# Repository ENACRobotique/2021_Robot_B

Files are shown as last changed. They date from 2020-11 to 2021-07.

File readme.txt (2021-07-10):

Code utilisée pour la coupe lors de l'année 2021 - sail the world.

Fonctionne assez aléatoirement pour le robot(probablement du à des soucis mécaniques).
Parfois, les états s'enchainent trop rapidement.

Documentation sur doxygen (lancer le index.html dans le dossier documentation_doxygen) pour savoir ce qui est réutilisable.

Flowchart global dans documentation_doxygen - vue_globale_code_2021

Le code utilisée lors de la coupe est dans Decision-IA, mais il est dégueu. Un code un peu plus clean avec la docu à jour pour usage ultérieur est(ou sera pour l'instant...) dans master.

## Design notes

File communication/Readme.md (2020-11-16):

# Communication

# Serialization

Messages serialization/deserialization is done with protobuf.

`def.proto` contains the messages definitions.

Generate python files with : `protoc --python_out=./ def.proto`

See python tutorial: https://developers.google.com/protocol-buffers/docs/pythontutorial

The teensy will use the [nanopb](https://github.com/nanopb/nanopb) library.

# Encapsulation

Encapsulation is handled by `serialcom.py` with the following format:

Encapsulation

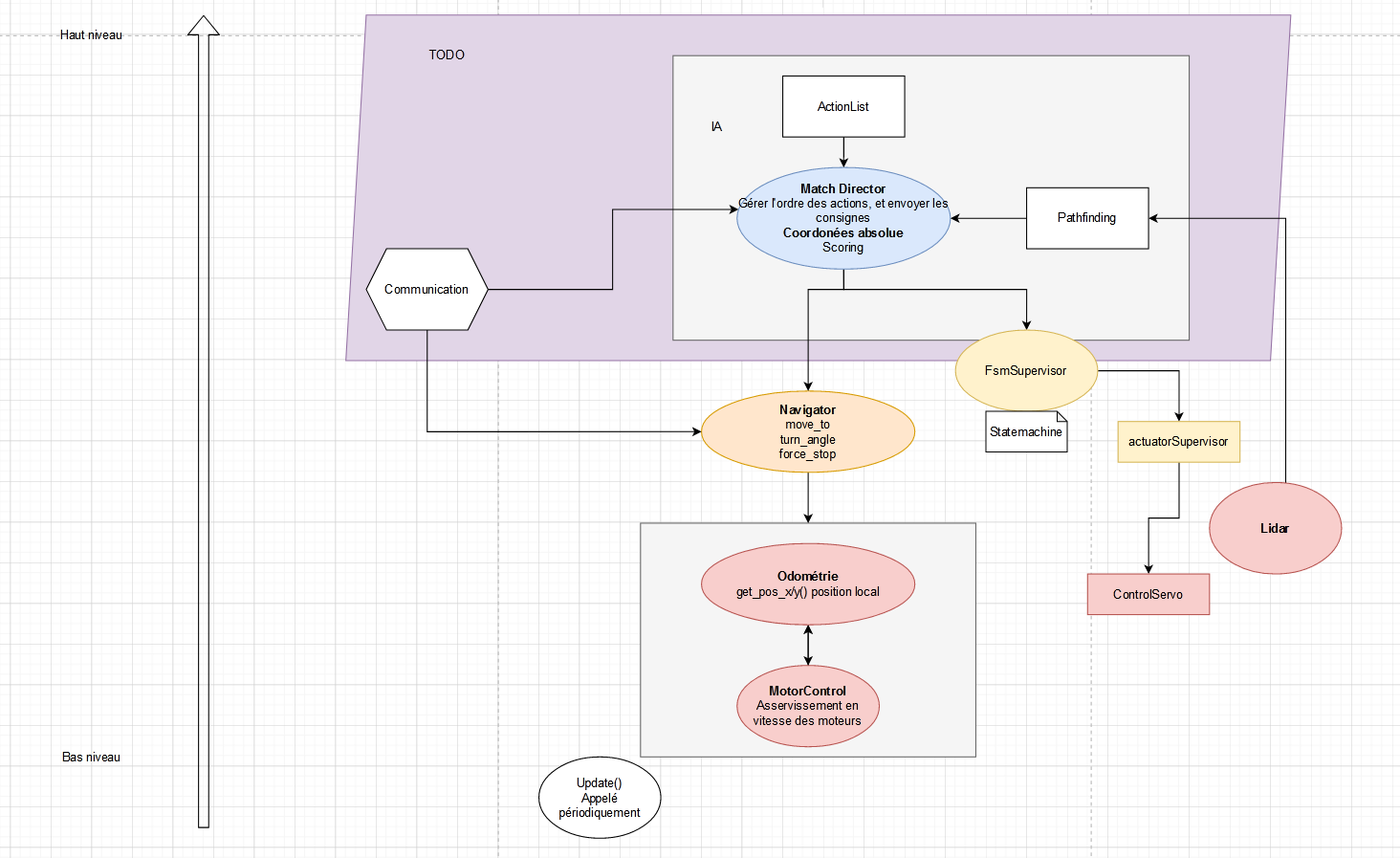
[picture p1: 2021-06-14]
vue_globale_code_2021.png

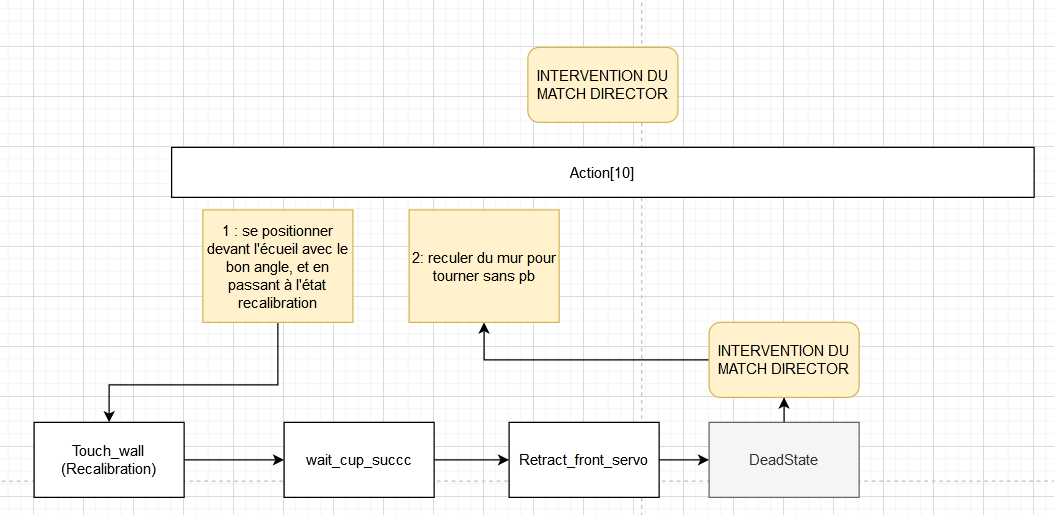
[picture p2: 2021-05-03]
base/src/ai/flowchat example matchdirector.png

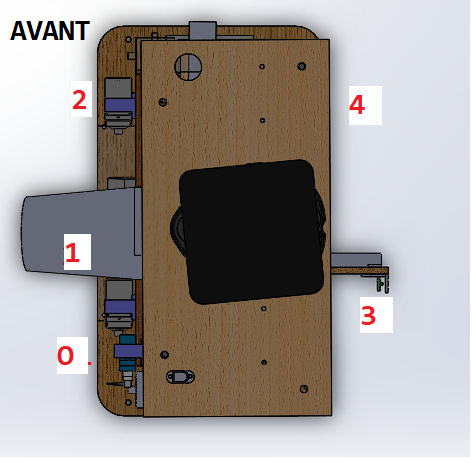
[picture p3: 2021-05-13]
kicad_robot/Numérotation servo capteur.png

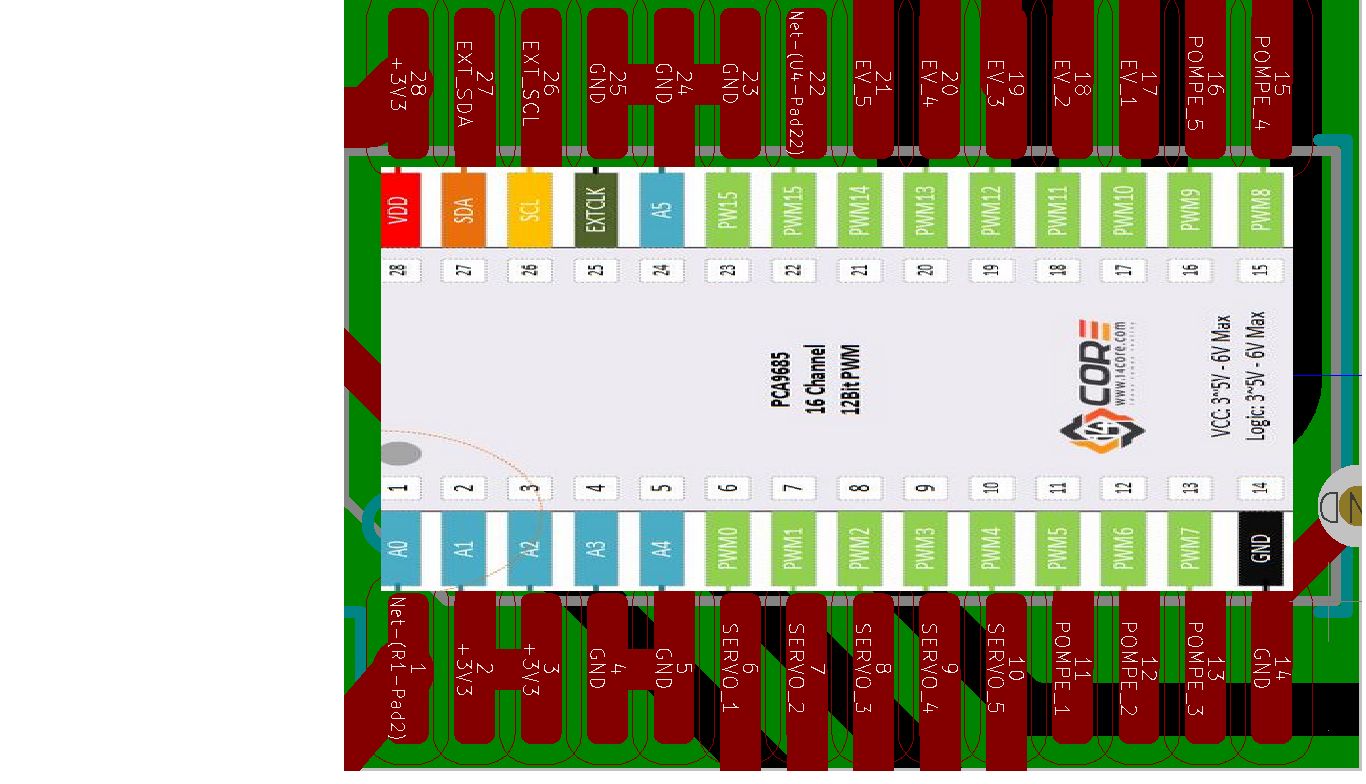
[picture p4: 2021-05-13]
kicad_robot/schéma PCA8595 PWM.png

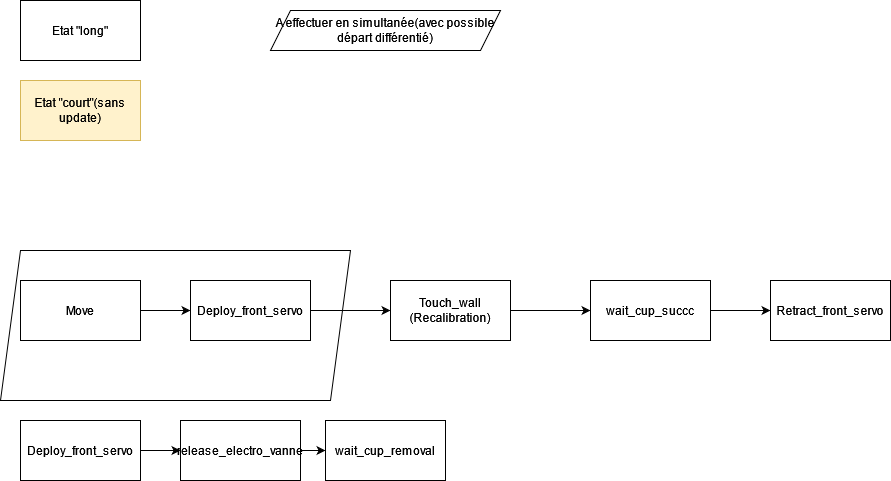
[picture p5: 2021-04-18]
base/src/stateMachine/diagramme state Machine.png

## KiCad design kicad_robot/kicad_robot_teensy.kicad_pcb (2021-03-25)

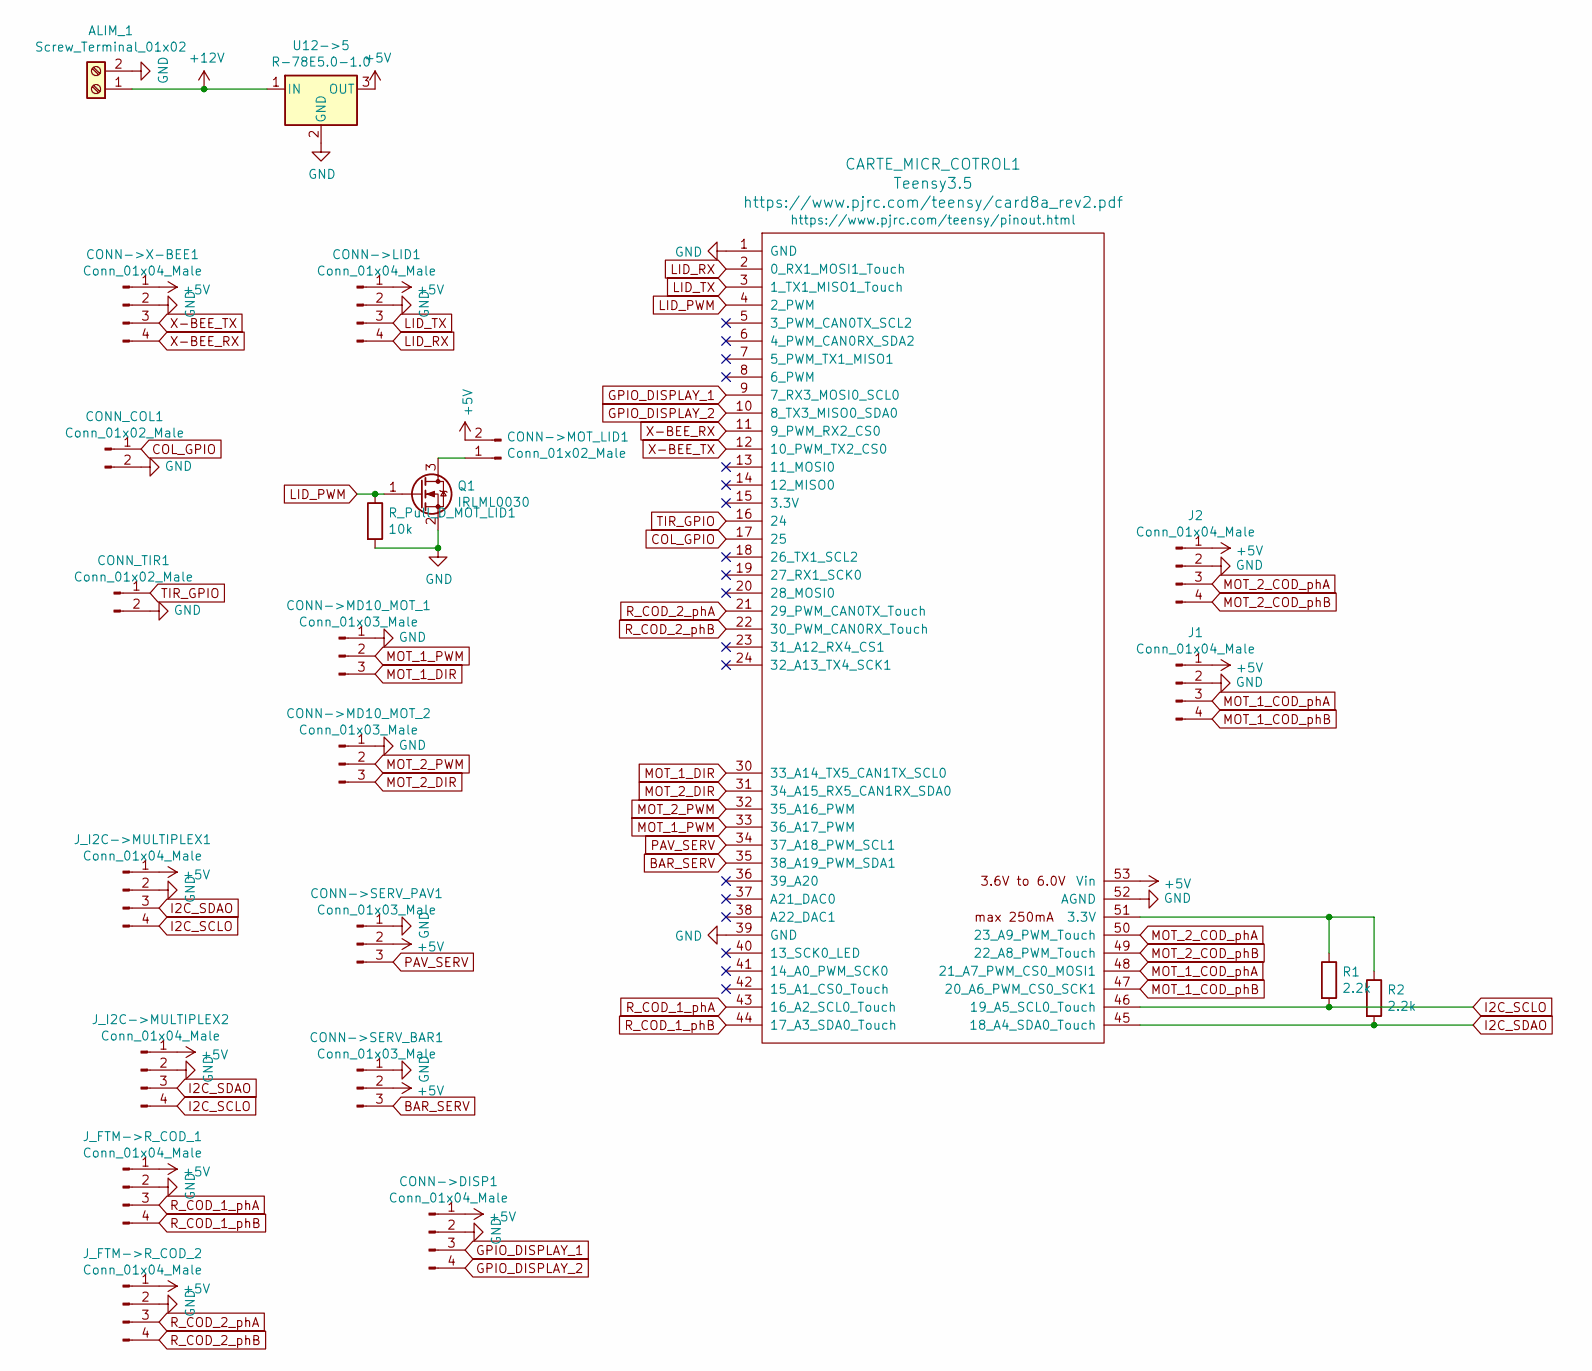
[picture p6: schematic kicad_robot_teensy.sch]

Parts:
ALIM_1: Screw_Terminal_01x02; TerminalBlock_bornier-2_P5.08mm
CARTE_MICR_COTROL1: Teensy3.5; Teensy35_36
CONN->DISP1: Conn_01x04_Male; JST_XH_B4B-XH-A_1x04_P2.50mm_Vertical
CONN->LID1: Conn_01x04_Male; JST_XH_B4B-XH-A_1x04_P2.50mm_Vertical
CONN->MD10_MOT_1, CONN->MD10_MOT_2: Conn_01x03_Male; JST_XH_B3B-XH-A_1x03_P2.50mm_Vertical
CONN->MOT_LID1: Conn_01x02_Male; JST_XH_B2B-XH-A_1x02_P2.50mm_Vertical
CONN->SERV_BAR1: Conn_01x03_Male; PinHeader_1x03_P2.54mm_Vertical
CONN->SERV_PAV1: Conn_01x03_Male; PinHeader_1x03_P2.54mm_Vertical
CONN->X-BEE1: Conn_01x04_Male; JST_XH_B4B-XH-A_1x04_P2.50mm_Vertical
CONN_COL1: Conn_01x02_Male; JST_XH_B2B-XH-A_1x02_P2.50mm_Vertical
CONN_TIR1: Conn_01x02_Male; JST_XH_B2B-XH-A_1x02_P2.50mm_Vertical
J1, J2: Conn_01x04_Male; JST_XH_B4B-XH-A_1x04_P2.50mm_Vertical
J_FTM->R_COD_1, J_FTM->R_COD_2: Conn_01x04_Male; JST_XH_B4B-XH-A_1x04_P2.50mm_Vertical
J_I2C->MULTIPLEX1, J_I2C->MULTIPLEX2: Conn_01x04_Male; JST_XH_B4B-XH-A_1x04_P2.50mm_Vertical
Q1: IRLML0030; SOT-23
R1, R2: 2.2k; R_0603_1608Metric_Pad0.98x0.95mm_HandSolder
R_Pull_D_MOT_LID1: 10k; R_0603_1608Metric_Pad0.98x0.95mm_HandSolder
U12->5: R-78E5.0-1.0; Converter_DCDC_RECOM_R-78E-0.5_THT

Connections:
+5V: CARTE_MICR_COTROL1.53 (Vin), CONN->DISP1.1, CONN->LID1.1, CONN->MOT_LID1.2, CONN->SERV_BAR1.2, CONN->SERV_PAV1.2, CONN->X-BEE1.1, J1.1, J2.1, J_FTM->R_COD_1.1, J_FTM->R_COD_2.1, J_I2C->MULTIPLEX1.1, J_I2C->MULTIPLEX2.1, U12->5.3 (OUT)
+12V: ALIM_1.1, U12->5.1 (IN)
BAR_SERV: CARTE_MICR_COTROL1.35 (38_A19_PWM_SDA1), CONN->SERV_BAR1.3
COL_GPIO: CARTE_MICR_COTROL1.17 (25), CONN_COL1.1
GND: ALIM_1.2, CARTE_MICR_COTROL1.1 (GND), CARTE_MICR_COTROL1.39 (GND), CARTE_MICR_COTROL1.52 (AGND), CONN->DISP1.2, CONN->LID1.2, CONN->MD10_MOT_1.1, CONN->MD10_MOT_2.1, CONN->SERV_BAR1.1, CONN->SERV_PAV1.1, CONN->X-BEE1.2, CONN_COL1.2, CONN_TIR1.2, J1.2, J2.2, J_FTM->R_COD_1.2, J_FTM->R_COD_2.2, J_I2C->MULTIPLEX1.2, J_I2C->MULTIPLEX2.2, Q1.2 (S), R_Pull_D_MOT_LID1.2, U12->5.2 (GND)
GPIO_DISPLAY_1: CARTE_MICR_COTROL1.9 (7_RX3_MOSI0_SCL0), CONN->DISP1.3
GPIO_DISPLAY_2: CARTE_MICR_COTROL1.10 (8_TX3_MISO0_SDA0), CONN->DISP1.4
I2C_SCLO: CARTE_MICR_COTROL1.46 (19_A5_SCL0_Touch), J_I2C->MULTIPLEX1.4, J_I2C->MULTIPLEX2.4, R1.2
I2C_SDAO: CARTE_MICR_COTROL1.45 (18_A4_SDA0_Touch), J_I2C->MULTIPLEX1.3, J_I2C->MULTIPLEX2.3, R2.2
LID_PWM: CARTE_MICR_COTROL1.4 (2_PWM), Q1.1 (G), R_Pull_D_MOT_LID1.1
LID_RX: CARTE_MICR_COTROL1.2 (0_RX1_MOSI1_Touch), CONN->LID1.4
LID_TX: CARTE_MICR_COTROL1.3 (1_TX1_MISO1_Touch), CONN->LID1.3
MOT_1_COD_phA: CARTE_MICR_COTROL1.48 (21_A7_PWM_CS0_MOSI1), J1.3
MOT_1_COD_phB: CARTE_MICR_COTROL1.47 (20_A6_PWM_CS0_SCK1), J1.4
MOT_1_DIR: CARTE_MICR_COTROL1.30 (33_A14_TX5_CAN1TX_SCL0), CONN->MD10_MOT_1.3
MOT_1_PWM: CARTE_MICR_COTROL1.33 (36_A17_PWM), CONN->MD10_MOT_1.2
MOT_2_COD_phA: CARTE_MICR_COTROL1.50 (23_A9_PWM_Touch), J2.3
MOT_2_COD_phB: CARTE_MICR_COTROL1.49 (22_A8_PWM_Touch), J2.4
MOT_2_DIR: CARTE_MICR_COTROL1.31 (34_A15_RX5_CAN1RX_SDA0), CONN->MD10_MOT_2.3
MOT_2_PWM: CARTE_MICR_COTROL1.32 (35_A16_PWM), CONN->MD10_MOT_2.2
unnamed: CARTE_MICR_COTROL1.51 (3.3V), R1.1, R2.1
unnamed: CONN->MOT_LID1.1, Q1.3 (D)
PAV_SERV: CARTE_MICR_COTROL1.34 (37_A18_PWM_SCL1), CONN->SERV_PAV1.3
R_COD_1_phA: CARTE_MICR_COTROL1.43 (16_A2_SCL0_Touch), J_FTM->R_COD_1.3
R_COD_1_phB: CARTE_MICR_COTROL1.44 (17_A3_SDA0_Touch), J_FTM->R_COD_1.4
R_COD_2_phA: CARTE_MICR_COTROL1.21 (29_PWM_CAN0TX_Touch), J_FTM->R_COD_2.3
R_COD_2_phB: CARTE_MICR_COTROL1.22 (30_PWM_CAN0RX_Touch), J_FTM->R_COD_2.4
TIR_GPIO: CARTE_MICR_COTROL1.16 (24), CONN_TIR1.1
X-BEE_RX: CARTE_MICR_COTROL1.11 (9_PWM_RX2_CS0), CONN->X-BEE1.4
X-BEE_TX: CARTE_MICR_COTROL1.12 (10_PWM_TX2_CS0), CONN->X-BEE1.3

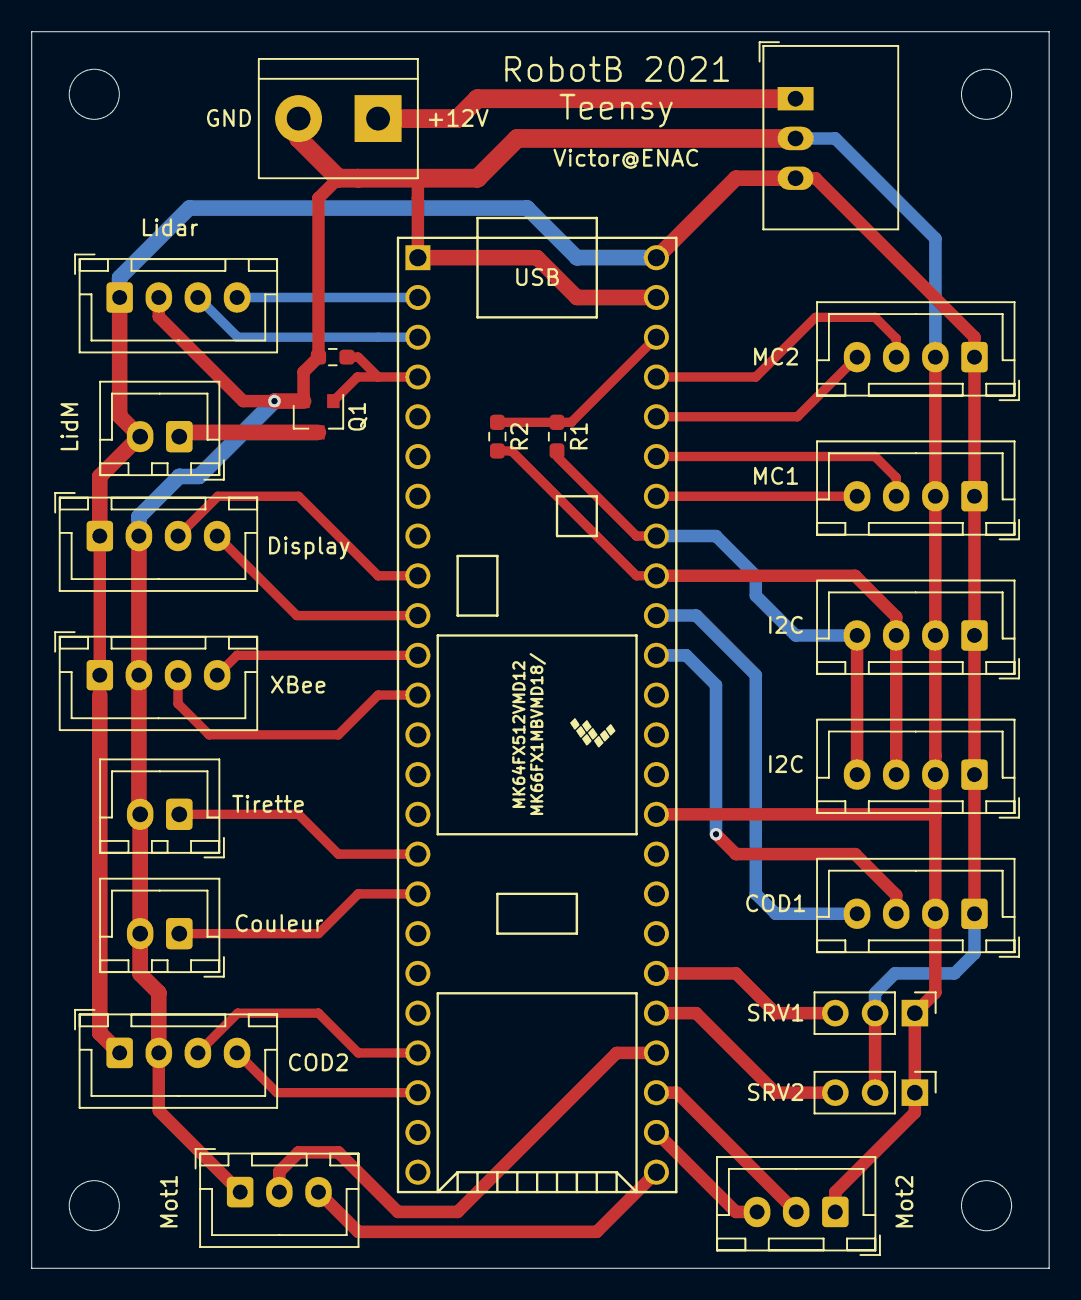
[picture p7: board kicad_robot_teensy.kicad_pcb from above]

Board: 2 copper layers, 65.0 x 79.0 mm, 23 parts (0 on the bottom side), 30 nets.

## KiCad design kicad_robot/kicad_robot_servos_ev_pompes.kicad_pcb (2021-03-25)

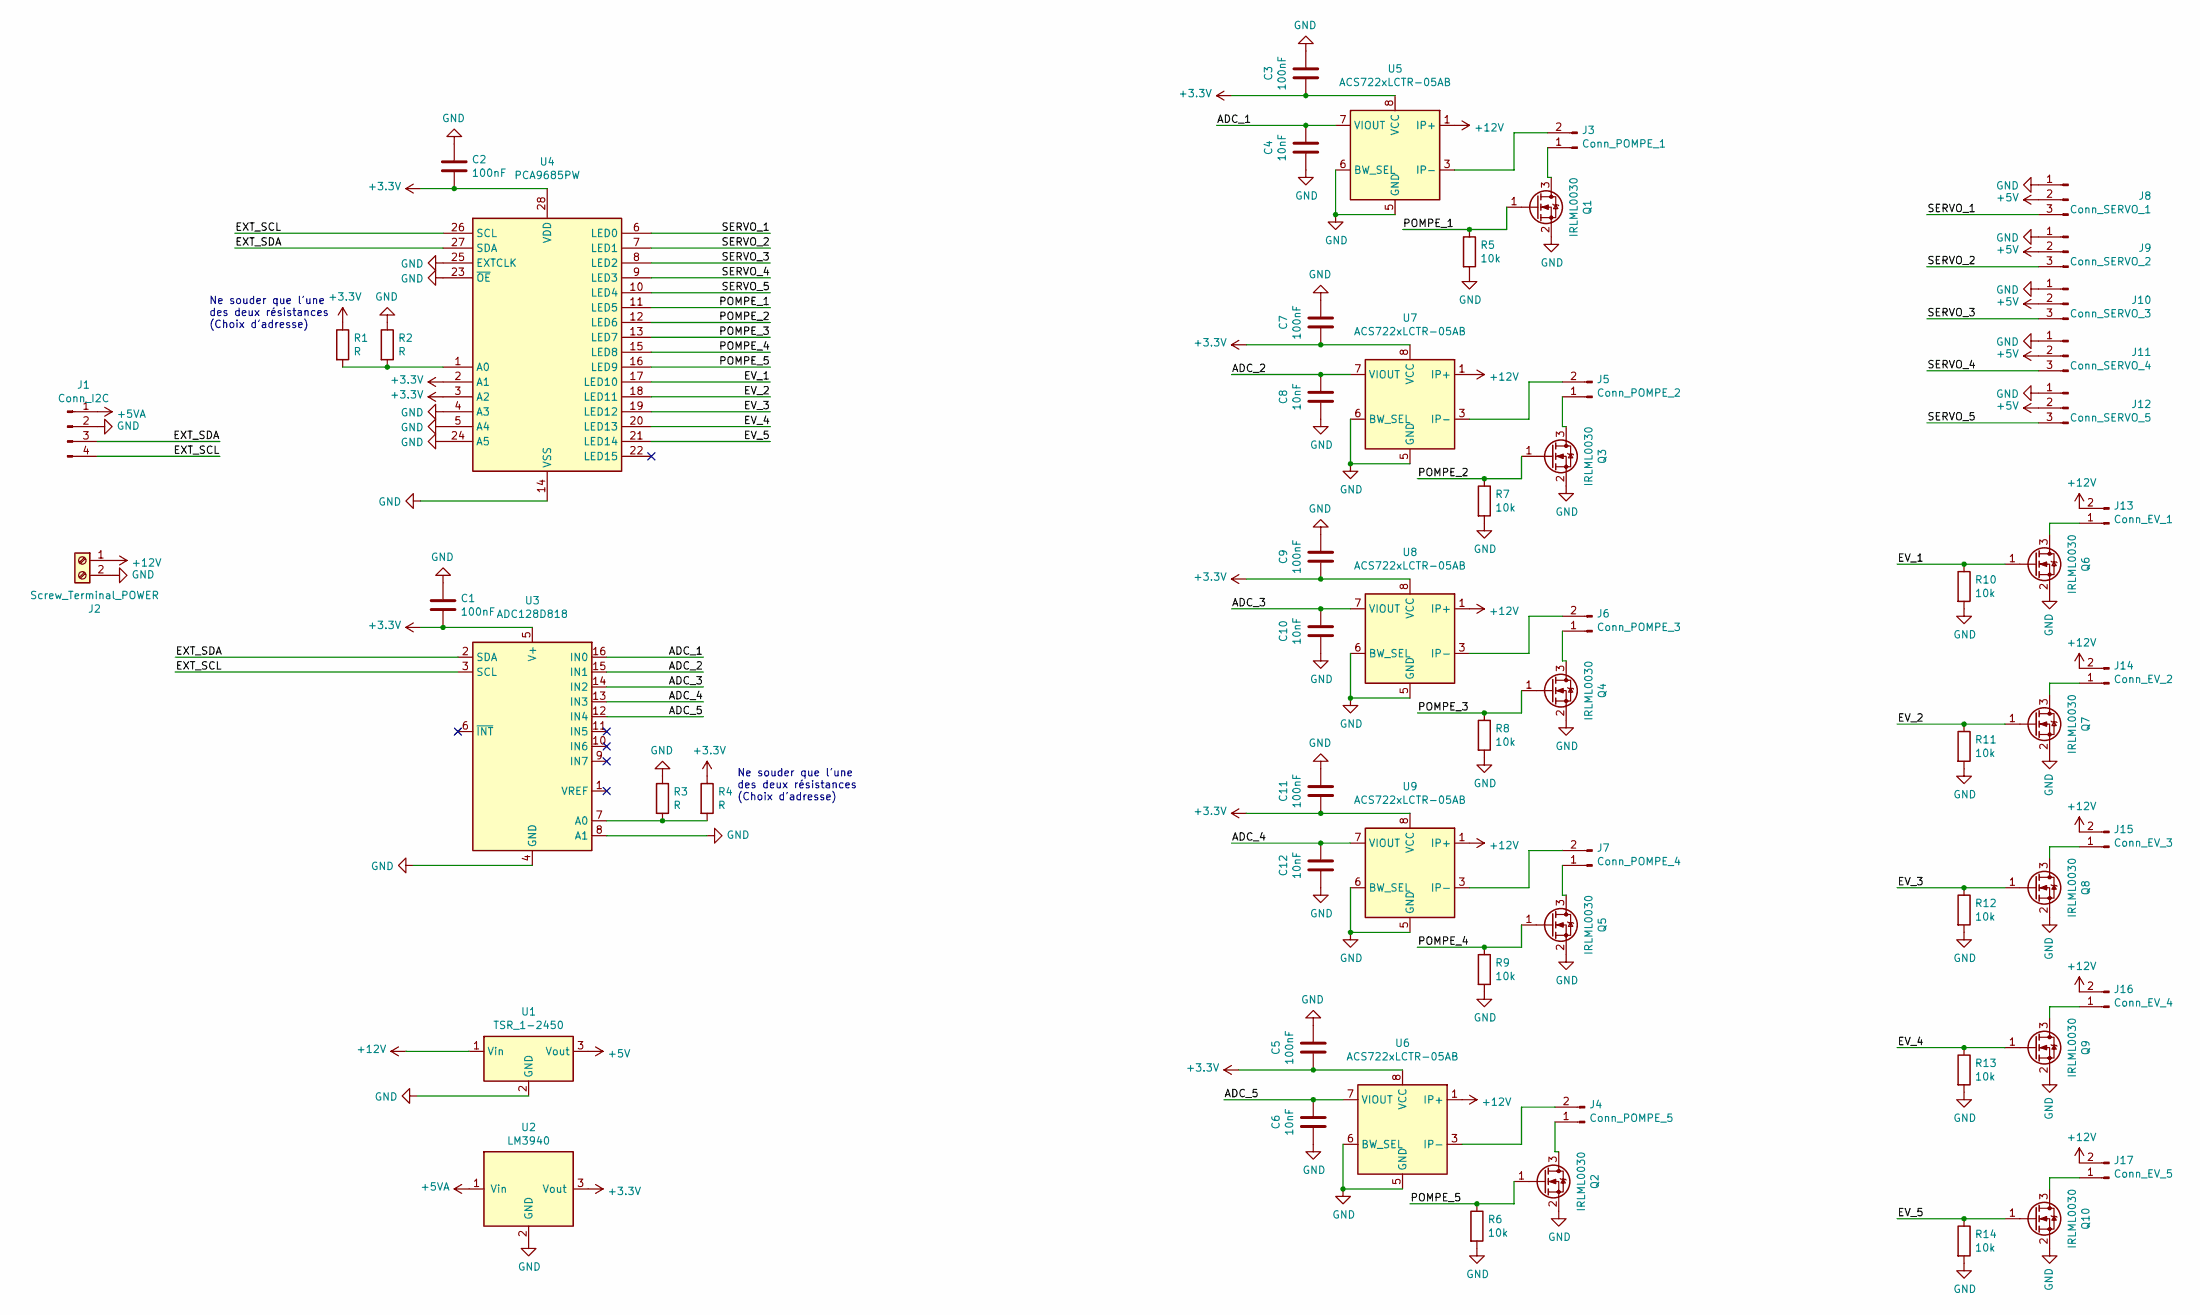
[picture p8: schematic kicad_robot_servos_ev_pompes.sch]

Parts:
C1, C2, C3, C5, C7, C9, C11: 100nF; C_0603_1608Metric_Pad1.08x0.95mm_HandSolder
C4, C6, C8, C10, C12: 10nF; C_0603_1608Metric_Pad1.08x0.95mm_HandSolder
J1: Conn_I2C; JST_XH_B4B-XH-A_1x04_P2.50mm_Vertical
J2: Screw_Terminal_POWER; TerminalBlock_bornier-2_P5.08mm
J3: Conn_POMPE_1; JST_XH_B2B-XH-A_1x02_P2.50mm_Vertical
J4: Conn_POMPE_5; JST_XH_B2B-XH-A_1x02_P2.50mm_Vertical
J5: Conn_POMPE_2; JST_XH_B2B-XH-A_1x02_P2.50mm_Vertical
J6: Conn_POMPE_3; JST_XH_B2B-XH-A_1x02_P2.50mm_Vertical
J7: Conn_POMPE_4; JST_XH_B2B-XH-A_1x02_P2.50mm_Vertical
J8: Conn_SERVO_1; PinHeader_1x03_P2.54mm_Vertical
J9: Conn_SERVO_2; PinHeader_1x03_P2.54mm_Vertical
J10: Conn_SERVO_3; PinHeader_1x03_P2.54mm_Vertical
J11: Conn_SERVO_4; PinHeader_1x03_P2.54mm_Vertical
J12: Conn_SERVO_5; PinHeader_1x03_P2.54mm_Vertical
J13: Conn_EV_1; JST_XH_B2B-XH-A_1x02_P2.50mm_Vertical
J14: Conn_EV_2; JST_XH_B2B-XH-A_1x02_P2.50mm_Vertical
J15: Conn_EV_3; JST_XH_B2B-XH-A_1x02_P2.50mm_Vertical
J16: Conn_EV_4; JST_XH_B2B-XH-A_1x02_P2.50mm_Vertical
J17: Conn_EV_5; JST_XH_B2B-XH-A_1x02_P2.50mm_Vertical
Q1, Q2, Q3, Q4, Q5, Q6, Q7, Q8, Q9, Q10: IRLML0030; SOT-23
R1, R2, R3, R4: R; R_0603_1608Metric_Pad0.98x0.95mm_HandSolder
R5, R6, R7, R8, R9, R10, R11, R12, R13, R14: 10k; R_0603_1608Metric_Pad0.98x0.95mm_HandSolder
U1: TSR_1-2450; Converter_DCDC_TRACO_TSR-1_THT
U2: LM3940; SOT-223-3_TabPin2
U3: ADC128D818; TSSOP-16_4.4x5mm_P0.65mm
U4: PCA9685PW; TSSOP-28_4.4x9.7mm_P0.65mm
U5, U6, U7, U8, U9: ACS722xLCTR-05AB; SOIC-8_3.9x4.9mm_P1.27mm

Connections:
+3V3: C1.2, C2.2, C3.2, C5.2, C7.2, C9.2, C11.2, R1.1, R4.1, U2.3 (Vout), U3.5 (V+), U4.2 (A1), U4.3 (A2), U4.28 (VDD), U5.8 (VCC), U6.8 (VCC), U7.8 (VCC), U8.8 (VCC), U9.8 (VCC)
+5V: J8.2, J9.2, J10.2, J11.2, J12.2, U1.3 (Vout)
+5VA: J1.1, U2.1 (Vin)
+12V: J2.1, J13.2, J14.2, J15.2, J16.2, J17.2, U1.1 (Vin), U5.1 (IP+), U5.2 (IP+), U6.1 (IP+), U6.2 (IP+), U7.1 (IP+), U7.2 (IP+), U8.1 (IP+), U8.2 (IP+), U9.1 (IP+), U9.2 (IP+)
/ADC_1: C4.1, U3.16 (IN0), U5.7 (VIOUT)
/ADC_2: C8.1, U3.15 (IN1), U7.7 (VIOUT)
/ADC_3: C10.1, U3.14 (IN2), U8.7 (VIOUT)
/ADC_4: C12.1, U3.13 (IN3), U9.7 (VIOUT)
/ADC_5: C6.1, U3.12 (IN4), U6.7 (VIOUT)
/EV_1: Q6.1 (G), R10.1, U4.17 (LED10)
/EV_2: Q7.1 (G), R11.1, U4.18 (LED11)
/EV_3: Q8.1 (G), R12.1, U4.19 (LED12)
/EV_4: Q9.1 (G), R13.1, U4.20 (LED13)
/EV_5: Q10.1 (G), R14.1, U4.21 (LED14)
/EXT_SCL: J1.4, U3.3 (SCL), U4.26 (SCL)
/EXT_SDA: J1.3, U3.2 (SDA), U4.27 (SDA)
/POMPE_1: Q1.1 (G), R5.1, U4.11 (LED5)
/POMPE_2: Q3.1 (G), R7.1, U4.12 (LED6)
/POMPE_3: Q4.1 (G), R8.1, U4.13 (LED7)
/POMPE_4: Q5.1 (G), R9.1, U4.15 (LED8)
/POMPE_5: Q2.1 (G), R6.1, U4.16 (LED9)
/SERVO_1: J8.3, U4.6 (LED0)
/SERVO_2: J9.3, U4.7 (LED1)
/SERVO_3: J10.3, U4.8 (LED2)
/SERVO_4: J11.3, U4.9 (LED3)
/SERVO_5: J12.3, U4.10 (LED4)
GND: C1.1, C2.1, C3.1, C4.2, C5.1, C6.2, C7.1, C8.2, C9.1, C10.2, C11.1, C12.2, J1.2, J2.2, J8.1, J9.1, J10.1, J11.1, J12.1, Q1.2 (S), Q2.2 (S), Q3.2 (S), Q4.2 (S), Q5.2 (S), Q6.2 (S), Q7.2 (S), Q8.2 (S), Q9.2 (S), Q10.2 (S), R2.1, R3.1, R5.2, R6.2, R7.2, R8.2, R9.2, R10.2, R11.2, R12.2, R13.2, R14.2, U1.2 (GND), U2.2 (GND), U3.4 (GND), U3.8 (A1), U4.4 (A3), U4.5 (A4), U4.14 (VSS), U4.23 (~OE), U4.24 (A5), U4.25 (EXTCLK), U5.5 (GND), U5.6 (BW_SEL), U6.5 (GND), U6.6 (BW_SEL), U7.5 (GND), U7.6 (BW_SEL), U8.5 (GND), U8.6 (BW_SEL), U9.5 (GND), U9.6 (BW_SEL)
unnamed: J3.1, Q1.3 (D)
unnamed: J3.2, U5.3 (IP-), U5.4 (IP-)
unnamed: J4.1, Q2.3 (D)
unnamed: J4.2, U6.3 (IP-), U6.4 (IP-)
unnamed: J5.1, Q3.3 (D)
unnamed: J5.2, U7.3 (IP-), U7.4 (IP-)
unnamed: J6.1, Q4.3 (D)
unnamed: J6.2, U8.3 (IP-), U8.4 (IP-)
unnamed: J7.1, Q5.3 (D)
unnamed: J7.2, U9.3 (IP-), U9.4 (IP-)
unnamed: J13.1, Q6.3 (D)
unnamed: J14.1, Q7.3 (D)
unnamed: J15.1, Q8.3 (D)
unnamed: J16.1, Q9.3 (D)
unnamed: J17.1, Q10.3 (D)
unnamed: R1.2, R2.2, U4.1 (A0)
unnamed: R3.2, R4.2, U3.7 (A0)

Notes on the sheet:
Ne souder que l'une des deux résistances (Choix d'adresse)

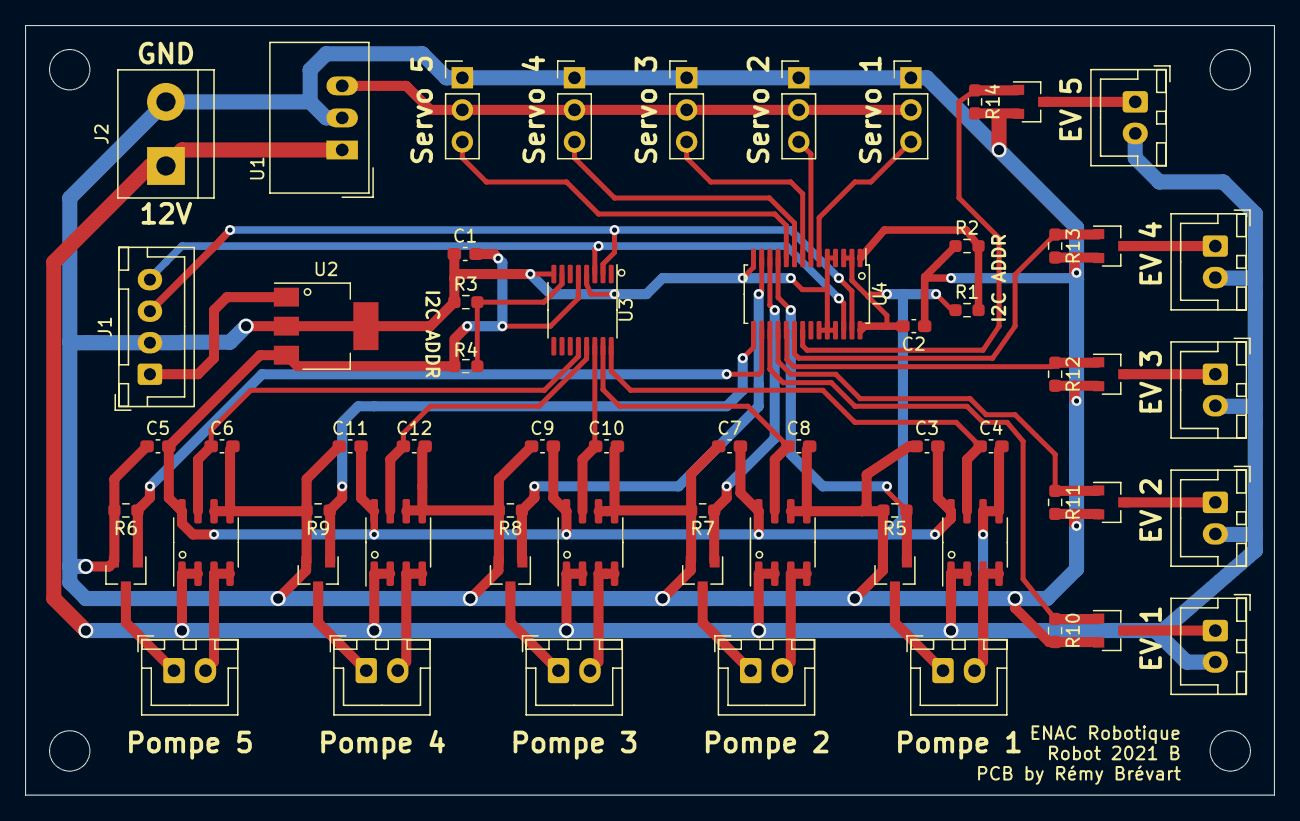
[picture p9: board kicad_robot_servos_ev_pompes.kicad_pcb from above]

Board: 2 copper layers, 99.0 x 61.0 mm, 62 parts (0 on the bottom side), 44 nets.

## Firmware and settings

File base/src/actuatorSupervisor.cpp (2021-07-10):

#include "Arduino.h"
#include "params.h"
#include "controlServo.h"
#include "actuatorSupervisor.h"
#include "Wire.h"
#include "Adafruit_PWMServoDriver.h"

namespace ActuatorSupervisor
{

	ControlServo armServos[5];
    ControlServo otherServos[2]; //[0] = Pavillon, [1] = tige horizontale

    Adafruit_PWMServoDriver pwm = Adafruit_PWMServoDriver(LED_DRIVER_ADDRESS, Wire);

    void init()
    {
        delay(100);
        Wire.begin();
        pwm.begin();
        pwm.setPWMFreq(SERVO_FREQ);
        delay(100);
        //arms servos
        
        /*for (int i = 0; i < 5; i++)
        {
            armServos[i].defInitAngle(150);
            armServos[i].init(servo_nb_to_pin(i), &pwm);
            switch_pompe(false, i);
            switch_ev(false, i);
        }*/

        for (int i = 2; i < 5; i++)
        {
            armServos[i].defInitAngle(150);
            armServos[i].init(servo_nb_to_pin(i), &pwm);
            switch_pompe(false, i);
            switch_ev(false, i);
        }

        //other servos
        otherServos[0].defInitAngle(SERVO_PAV_ANGLE_RTRCTED);
        //otherServos[0].init(SERVO_PAV, NULL); 
        otherServos[0].init(SERVO1, &pwm);
        
        otherServos[1].defInitAngle(SERVO_BAR_ANGLE_RTRCTED);
        //otherServos[1].init(SERVO_BAR, NULL); 
        otherServos[1].init(SERVO2, &pwm); 

        //TODO : pinMode nécessaire ou non
        //pinMode(POMPE, OUTPUT);
        //pinMode(VANN, OUTPUT);

        //multiplexers
        //delay(10);
        //pwm.begin();
        //pwm.setPWMFreq(PWM_FREQUENCY);    
        SerialCtrl.println("init done for actuatorSupervisor ! ");
    }

    void deploy_pav()
    {
        otherServos[0].moveServo(SERVO_PAV_ANGLE_DPLOYED);
        //SerialCtrl.println("pavillon - ordre de déploiement");
    }
    void retract_pav()
    {
        otherServos[0].moveServo(SERVO_PAV_ANGLE_RTRCTED);
    }
    void deploy_bar()
    {
        otherServos[0].moveServo(SERVO_BAR_ANGLE_DPLOYED);
    }
    void retract_bar()
    {
        otherServos[0].moveServo(SERVO_BAR_ANGLE_RTRCTED);
    }

    void switch_pompe(bool isOn, int pompe)
    {
        SerialCtrl.println("ENABLE POMPE NOT TESTED");
        int start_pwm = (isOn) ? 4096 : 0;
        int end_pwm = (isOn) ? 0 : 4096;
        pwm.setPWM(pompe_nb_to_pin(pompe), start_pwm, end_pwm);
        //int pin = pompe_nb_to_pin(pompe);
    }
    void switch_ev(bool isOn, int ev)
    {
        SerialCtrl.println("ENABLE EV NOT TESTED");
        int start_pwm = (isOn) ? 4096 : 0;
        int end_pwm = (isOn) ? 0 : 4096;
        pwm.setPWM(ev_nb_to_pin(ev), start_pwm, end_pwm);
    }
    int servo_nb_to_pin(int servo) 
    /* return 0 if servo_nb not between 0 & 4 included */
    {
        switch (servo)
        {
        case 0:
            return SERVO1;
        case 1:
            return SERVO2;
        case 2:
            return SERVO3;
        case 3:
            return SERVO4;
        case 4:
            return SERVO5;
        default:
            return 0;
        }
    }
    int pompe_nb_to_pin(int pompe) 
    /* return 0 if servo_nb not between 1 & 5 included */
    {
        switch (pompe)
        {
        case 0:
            return POMPE1;
        case 1:
            return POMPE2;
        case 2:
            return POMPE3;
        case 3:
            return POMPE4;
        case 4:
            return POMPE5;
        default:
            return 0;
        }
    }

    int ev_nb_to_pin(int ev) 
    /* return 0 if servo_nb not between 1 & 5 included */
    {
        switch (ev)
        {
        case 0:
            return EV1;
        case 1:
            return EV2;
        case 2:
            return EV3;
        case 3:
            return EV4;
        case 4:
            return EV5;
        default:
            return 0;
        }
    }

}
ActuatorSupervisor::CupColor ActuatorSupervisor::get_color(int sensor_nb) {
    SerialCtrl.println("get_color non implémenté !");
    return NONE;    
}


/*

void setup() {
  Serial.begin(9600);
  Serial.println("GPIO test!");

  pwm.begin();
  pwm.setPWMFreq(1000);  // Set to whatever you like, we don't use it in this demo!

  // if you want to really speed stuff up, you can go into 'fast 400khz I2C' mode
  // some i2c devices dont like this so much so if you're sharing the bus, watch
  // out for this!
  Wire.setClock(400000);
}

void loop() {
  // Drive each pin in a 'wave'
  for (uint8_t pin=0; pin<16; pin++) {
    pwm.setPWM(pin, 4096, 0);       // turns pin fully on
    delay(100);
    pwm.setPWM(pin, 0, 4096);       // turns pin fully off
  }
}

*/

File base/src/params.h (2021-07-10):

/*
 * params.h
 *
 *  Created on: 18 mars 2018
 *      Author: elie
 */


#ifndef PARAMS_H_
#define PARAMS_H_

#define VOLT_TO_DIST(volt) (13 * pow (volt  * 0.0048828125, -1)) 
#define DEBUG_MATCH_DIRECTOR
//#define DEBUG_ODOMETRY

#ifndef DEBUG_NO_ARDUINO
    #include "Arduino.h"


    // 

    // ** Serials ports ** //
    //#define SerialDebug = Serial;
    //#define SerialCtrl = Serial5;
    //(using stream instead of HardwareSerial because Serial doesn't inherit it)

    //config normale :
    static Stream& SerialDebug = Serial; // used for debug printing - Serial1 -> USB 
    static HardwareSerial& SerialCtrl = Serial2;//Serial2; //used for Xbee, sending and receiveing remotly instructions, remote debug 

    //config debug : 
    //static Stream& SerialCtrl = Serial; // used for debug printing - Serial1 -> USB 
    //static HardwareSerial& SerialDebug = Serial2;//Serial2; //used for Xbee, sending and receiveing remotly instructions, remote debug


    
    static HardwareSerial& SerialLidar = Serial1;
#endif

const int ARUCO_ID = 1;

const unsigned long TIME_RACE = 100000;

#pragma region pins physiques

const int MOT_ENCODEUR1_A = 21;
const int MOT_ENCODEUR1_B = 20;
const int MOT_ENCODEUR2_A = 23;
const int MOT_ENCODEUR2_B = 22;

const int WHEEL_ENCODEUR1_A = 16;//16;
const int WHEEL_ENCODEUR1_B = 17;//17;
const int WHEEL_ENCODEUR2_A = 29;//29;
const int WHEEL_ENCODEUR2_B = 30;//30;


const int MOT1_PWM = 35;//36;
const int MOT1_DIR = 34;//33;
const int MOT2_PWM = 36;//35;
const int MOT2_DIR = 33;//34;

//const int BATT_CHARGE = 37;

const int SERVO_PAV = 37;
const int SERVO_BAR = 38;

const int DISPALY_CLK = 9;
const int DISPLAY_DATA = 10;

//PCA 9685PW - not pin from teensy !
const int EV5 = 14; //EV = ElectroVanne
const int EV4 = 13;
const int EV3 = 12;
const int EV2 = 11;
const int EV1 = 10;
const int POMPE5 = 9;
const int POMPE4 = 8;
const int POMPE3 = 7;
const int POMPE2 = 6;
const int POMPE1 = 5;
const int SERVO5 = 4;
const int SERVO4 = 3;
const int SERVO3 = 2;
const int SERVO2 = 1;
const int SERVO1 = 0;

//Pins from I2C multiplexer, not from teensy :
const int COLOR_SENSOR_1 = 0;//TODO

const int MOT_LIDAR = 2;
const int COLOR = 25;
const int TIRETTE = 24;
const int DISPLAY1 = 7;
const int DISPLAY2 = 8;

#pragma endregion 

#pragma region addresses I2C et params driver de led
const int LED_DRIVER_ADDRESS = 0x46; //0x46 is configured, 0x70 is "all called led address" (don't use it )
const int PWM_FREQUENCY = 50;
#pragma endregion

const float SPEED_MAX = 500.0f; //0.5f;
const float OMEGA_MAX = 1.4f;


const int EMERGENCY_BRAKE = 1800;
const int ACCEL_MAX = 500;
const int ACCEL_MAX_THROW = 100;
const int SPEED_MAX_CRUISE = 350;

const int ACCEL_MAX_CAP = 100;
const int SPEED_MAX_CAP = 100;

const float ACCEL_OMEGA_MAX_CRUISE = 1;
const float OMEGA_MAX_CRUISE = 1.5;

const float ACCEL_OMEGA_MAX_CAP = 0.3;
const float OMEGA_MAX_CAP = 0.5;

const float ACCEL_OMEGA_MAX = 1;


const float ADMITTED_OMEGA_ERROR = 0.03;
const float ADMITTED_SPEED_ERROR = 10;

const float ADMITTED_POSITION_ERROR = 5; //3
const float ADMITTED_ANGLE_ERROR = 0.01;
const float ADMITTED_DEG_ANGLE_ERROR = 5;

//const float MAX_DRIFT = 0.1;
//const float WHEEL_DIAMETER = 55.0;
const float robot_center_x = 150.f; // largeur / 2
const float WHEELBASE = 169.;
const float INCR_TO_MM = 0.3414969475;   //PI*WHEEL_DIAMETER/805.12; ou divisé par 701 pour l'encodeur des moteurs 12V
const float INCR_TO_MM_1 = INCR_TO_MM * 1;
const float INCR_TO_MM_2 = INCR_TO_MM * 1;
const float CODER_WHEEL_BASE = 222.;
const float CODER_INCR_TO_MM = 0.061359232;   //PI*WHEEL_DIAMETER/805.12; ou divisé par 701 pour l'encodeur des moteurs 12V
const float CODER_INCR_TO_MM_1 = CODER_INCR_TO_MM * 1;
const float CODER_INCR_TO_MM_2 = CODER_INCR_TO_MM * 1;
//const float INCR_TO_TOURS = 1/805.12;
const float CONTROL_PERIOD = 0.02;
const float NAVIGATOR_PERIOD = 0.05;
const float COMMUNICATION_PERIOD = 0.1;
const float STATE_PERIOD = 0.1;

const unsigned long THROW_DURATION = 20000;
const unsigned long SERVO_MOVEMENT_DURATION = 1000;
const unsigned long DETECTION_STOP_TIME = 1500;


enum sensors {IR1=33,IR2,IR3,IR4,IR5,IR6,IR_test};
const sensors IR_sel=IR_test;


//params de capture ecocup
const float dist_min=5,dist_max=20;//valeurs initial turn
const float delta_step_forward=20;//mm
const float nominal_delta_rot=10;//degres
const float dist_opt=4.5;

//ARMS : 
const int SERVO_ANGLE_RETRACTED = 150;
const int SERVO_ANGLE_DEPLOYED = 60;

//servos : 
const int SERVO_PAV_ANGLE_RTRCTED = 15;
const int SERVO_PAV_ANGLE_DPLOYED = 105;

const int SERVO_BAR_ANGLE_RTRCTED = 0;
const int SERVO_BAR_ANGLE_DPLOYED = 180;


// const int NB_US = 4;
#endif /* PARAMS_H_ */

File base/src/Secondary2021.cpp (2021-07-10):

/**
 * @file Secondary2021.cpp
 * @author jonathan Muchler
 * @brief 
 * @date 2021-06-12
 * 
 * @image html vue_globale_code_2021.png "vue globale du code - au debut juin 2021"
 */

#include "Arduino.h" 
#include "odometry.h"
#include "motorControl.h" 
#include "params.h" 
#include "Metro.h"

#include "communication.h"
#include "navigator.h"
#include "FsmSupervisor.h"
#include "actuatorSupervisor.h"
#include "ai/MatchDirector.h"


#include "examples/servoTest.h" 
#include "examples/asservissementMoteur.h" 
#include "examples/debugTest.h" 
#include "examples/testXbee.h" 
#include "pathfinding.h"
#include "lidar/Lidar.h"
//#include "raspberryParser.h"
#include "DisplayController.h"

Metro controlTime = Metro((unsigned long)(CONTROL_PERIOD * 1000));
Metro debugLed = Metro(2000);
Metro navTime = Metro((unsigned long)(NAVIGATOR_PERIOD * 1000)); //2000
Metro TestTime = Metro((unsigned long)5000);
Metro commXBee = Metro((unsigned long)(COMMUNICATION_PERIOD * 1000));
Metro stateTime = Metro((unsigned long)(STATE_PERIOD * 1000));

float sp[4] = {0, 3.14f, 0, -3.14f};
int i = 0;

#include "ai/ActionsList.h"
void setup() {
  //pinMode(LED_BUILTIN, OUTPUT);
  //pinMode(11, OUTPUT);
  //testXbee::init();
    Serial2.begin(57600);
    Serial.begin(57600);
    //SerialDebug.begin(57600);
    SerialDebug.println("test SerialDebug 1");
    SerialCtrl.println("test SerialCtrl 1");
    //#ifdef DEBUG_ASSERVISSEMENT
      //Serial.println("cons_speed cons_omega actual_speed actual_omega");
    //#endif
    
    //while(!Serial) {} 
    /*
    Serial.println("initialization serialDebug");
    Serial.println("timer du match mis à 10s !!");
    SerialCtrl.println("initialization serialCtrl");
    */
  //Wire.begin();
  
  controlTime.reset();
	debugLed.reset();
	navTime.reset();
	TestTime.reset();
	odometry_motor.init();
  odometry_wheel.init();
	MotorControl::init();
  fsmSupervisor.init();
  ActuatorSupervisor::init();
  MatchDirector::init(); 

  debugTest::scanSerial();
  displayController.init();

  //while (!Serial);
  SerialCtrl.println("test serialctrl");
  Serial.println("test serial");
  //ActuatorSupervisor::switch_pompe(true, 0);
  //navigator.move_to(500.f, 0.f);

  //Serial2.println("Scanner debut");
  //debugTest::scanSerial();
 
}

void loop() {
  
 
  //testXbee::update();
    
      if(navTime.check())
    {
        //ActuatorSupervisor::switch_pompe(true, 2);
      navigator.update();
    
    }

		if(controlTime.check()) {
      Odometry::update_reading(&odometry_motor, &odometry_wheel);
      MotorControl::update();
		} 

    
    if(commXBee.check())
    {
      Communication::update();
    }
    if(stateTime.check())
    {   
      MatchDirector::update();      
      fsmSupervisor.update();

    }
 
    if(TestTime.check())
    {
      //asservissementMoteur::update();
    }
  //send_odom_report(12.2, 34.2, 14.8);
  //delay(800);


} 

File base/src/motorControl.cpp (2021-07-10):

/*
 * motorControl.cpp
 *
 *  Created on: 20 mars 2018
 *      Author: elie
 */


#include "odometry.h"
#include "Arduino.h"
#include "params.h"
#include "motorControl.h"
#include "utils.h"

// int clamp(int inf, int sup, float x) {
// 	return min(sup, max(inf, x));
// }

int direction_sign(int nb) {
	if(nb>0) {
		return 0;
	}
	else {
		return 1;
	}
}

namespace MotorControl {

	float cons_speed=0;
	float cons_omega=0;
	
	float Ki_speed = 0.15; //0.2
	float Kp_speed = 0.4; //0.5
	float Kd_speed = 0.05; //0.2
	float Ki_omega = 10;//15;
	float Kp_omega = 40;//10;
	float Kd_omega = 10;//10;

/*
	float Ki_speed = 0.2;//0.2;
	float Kp_speed = 0.5;//0.5;
	float Kd_speed = 0;
	float Ki_omega = 10;//15  20;
	float Kp_omega = 10;//75  30;
	float Kd_omega = 0;
	*/
	float error_integrale_speed=0.01;
	float error_integrale_omega=0;

	float delta_speed=0;
	float delta_omega=0;
	float prev_speed_error=0;
	float prev_omega_error=0;

	void set_cons(float speed, float omega) {
		cons_speed = speed;
		cons_omega = omega;
	}

	float get_cons_speed(){
		return cons_speed;
	}

	float get_cons_omega(){
		return cons_omega;
	}

	void init() {
		pinMode(MOT1_DIR, OUTPUT);
		pinMode(MOT1_PWM, OUTPUT);
		pinMode(MOT2_DIR, OUTPUT);
		pinMode(MOT2_PWM, OUTPUT);
		cons_omega = cons_speed = 0;
		error_integrale_omega = error_integrale_speed = 0;
		prev_omega_error = prev_speed_error = 0;


	}
	void testmoteur(int cmde1, int cmde2) {
		analogWrite(MOT1_PWM, abs(cmde1));
		digitalWrite(MOT1_DIR, direction_sign(cmde1));
		analogWrite(MOT2_PWM, abs(cmde2));
		digitalWrite(MOT2_DIR, direction_sign(cmde2));
	}

	
	void update() {

		float error_speed = cons_speed - odometry_motor.get_speed();
		error_integrale_speed += error_speed;
		delta_speed = error_speed - prev_speed_error;
		prev_speed_error = error_integrale_speed;
		float cmd_speed = Kp_speed * error_speed + Ki_speed * error_integrale_speed + Kd_speed * delta_speed;

		float error_omega = cons_omega - odometry_motor.get_omega();
		error_integrale_omega += error_omega;
		delta_omega = error_omega - prev_omega_error;
		prev_omega_error = error_omega;
		//error_integrale_omega = clamp(-100,100,error_integrale_omega);
		float cmd_omega = Kp_omega * error_omega + Ki_omega * error_integrale_omega + Kd_omega * delta_omega;

		int cmd_mot1 = clamp(-255.f, 255.f, -cmd_speed - cmd_omega);
		int cmd_mot2 = -clamp(-255.f, 255.f, -cmd_speed + cmd_omega);

		analogWrite(MOT1_PWM, abs(cmd_mot1));
		digitalWrite(MOT1_DIR, direction_sign(cmd_mot1));
		analogWrite(MOT2_PWM, abs(cmd_mot2));
		digitalWrite(MOT2_DIR, direction_sign(cmd_mot2));

	//#ifdef DEBUG_ASSERVISSEMENT 
	//a utiliser avec traceur série 
	
	//SerialDebug.print(cons_speed);
	//SerialDebug.print("\t");
	SerialDebug.print(cons_omega);
	SerialDebug.print("\t");
	//SerialDebug.print(odometry_motor.get_speed());
	//SerialDebug.print("\t");
	SerialDebug.println(odometry_motor.get_omega()); 
	//#endif
/*
	
		SerialDebug.print("cmd mot 2 & 1 : ");
		SerialDebug.print(cmd_mot2);
		SerialDebug.print("\t");
		SerialDebug.print(cmd_mot1);
		SerialDebug.print("\t");
		//SerialDebug.println(); */
	}
}

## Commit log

2020-11-09 Description d'une possible l'architecture du projet modification de la hiérarchie du code pour refléter cette architecture
2020-11-09 (ajout d'un saut de ligne)
2020-11-16 Adds template teensy project with basic communication.
2021-02-11 Ajout du répertoire du projet kicad
    [kicad_robot.kicad_pcb, kicad_robot.sch]
2021-02-15 Avancement sur la carte
    [kicad_robot.sch]
2021-02-20 Ajout Petite Carte
    [kicad_robot_small.kicad_pcb, kicad_robot_small.sch]
2021-02-22 Petit avancement
    [kicad_robot.sch]
2021-02-22 ajout des copies des librairies teensy utilisées
2021-02-22 mise à jour
    [kicad_robot_teensy.sch]
2021-02-22 Séparation de l'alimentation du LM3940
    [kicad_robot_servos_ev_pompes.sch]
2021-02-22 Modif mineure LM3940 (épaisseur trait)
    [kicad_robot_servos_ev_pompes.sch]
2021-02-22 Reversed some connectors
    [kicad_robot_servos_ev_pompes.sch]
2021-02-22 Capa de découplage PCA
    [kicad_robot_servos_ev_pompes.sch]
2021-02-22 Ajout des derniers composants
    [kicad_robot_teensy.sch]
2021-02-22 Footprint attribution
    [kicad_robot_servos_ev_pompes.sch]
2021-02-22 Created netlist and imported in pcb
    [kicad_robot_servos_ev_pompes.kicad_pcb]
2021-02-22 Ajout des footprint carte teensy
    [kicad_robot_teensy.sch]
2021-02-23 Finalisation du fichier SCH/ Début fichier PCB
    [kicad_robot_teensy.kicad_pcb, kicad_robot_teensy.sch]
2021-02-24 Routage de la carte Teensy V1.0
    [kicad_robot_teensy.kicad_pcb]
2021-02-25 Placement des composants
    [kicad_robot_servos_ev_pompes.kicad_pcb]
2021-02-25 Réarrangement des composants / Routage (v1)
    [kicad_robot_servos_ev_pompes.kicad_pcb]
2021-02-25 Ajout de sérigraphie pour repérer les numéros d'équipements facilement sur la carte
    [kicad_robot_servos_ev_pompes.kicad_pcb]
2021-03-04 Carte Teensy V2.0
    [kicad_robot_teensy.kicad_pcb, kicad_robot_teensy.sch]
2021-03-04 Routage V2 de la carte servos/ev/pompes
    [kicad_robot_servos_ev_pompes.kicad_pcb, kicad_robot_servos_ev_pompes_v1.kicad_pcb]
2021-03-11 copie code des 2A
2021-03-11 Routage Carte Servos/EV/Pompes v3 (avec mounting holes)
    [kicad_robot_servos_ev_pompes.kicad_pcb]
2021-03-11 Déplacement de quelques labels (changement mineur)
    [kicad_robot_servos_ev_pompes.kicad_pcb]
2021-03-13 Calage des edge cuts et des mounting holes sur grille 1mm, épaissisement et décalage tracks
    [kicad_robot_servos_ev_pompes.kicad_pcb]
2021-03-13 Écartement de vias et pistes encore trop proches
    [kicad_robot_servos_ev_pompes.kicad_pcb]
2021-03-14 Passage de certaines tracks en bottom, supression de vias inutiles
    [kicad_robot_servos_ev_pompes.kicad_pcb]
2021-03-14 Support pins (mais non logiciel) de 4 encodeurs
2021-03-15 Agrandissement des vias (source des mosfets, GND des résistances EV), cache des REF**
    [kicad_robot_servos_ev_pompes.kicad_pcb]
2021-03-16 ajout code lidar 2019
2021-03-16 Cache de labels inutiles
    [kicad_robot_servos_ev_pompes.kicad_pcb]
2021-03-16 Teensy V2.1: Carte presque prête
    [kicad_robot_teensy.kicad_pcb, kicad_robot_teensy.sch]
2021-03-25 Carte Tennsy version finale
    [kicad_robot_teensy.kicad_pcb]
2021-03-25 Génération Gerber Carte Servos
    [kicad_robot_servos_ev_pompes-B_Cu.gbr, kicad_robot_servos_ev_pompes-B_Mask.gbr, kicad_robot_servos_ev_pompes-B_Paste.gbr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]
2021-03-25 Ignore les zips de gerber_servos et gerber_teensy
2021-03-25 copie des fichiers du repo secondaire/2019 pour modification
2021-03-25 Moved lidar tests to another projects in separate workspace
2021-03-25 code basique pour essayer de récupérer les données du lidar
2021-03-25 des tests
2021-03-26 Changement vers teensy 3.5, essais
2021-04-03 ajout abstract state servo
2021-04-03 abstract state, regroupement des Serial dans params.h
2021-04-22 wip lidar
2021-05-03 flowchart ajout
2021-05-12 ajout de pins manquant
2021-05-13 avancement actuator
2021-05-13 solved merge problem params.h
    [params.h]
2021-05-13 Refactorisation pour state movement arm
2021-05-13 refactorisation de MoveServo
2021-05-21 ajout code ctrl servo PCA
2021-05-24 modifs du jeudi 20 mai (bcp de bugs, et pas bcp de progrès)
    [params.h]
2021-05-24 Ajout d'un code de test de recallibration
2021-05-25 recalibration enfaite pas besoin de timer, géré ds fsm
2021-05-27 wheelbase coder
2021-05-28 update time calculation, beginning to transition odometry to class
2021-06-01 Probléme pour fsmSupervisor -> bloque Probléme pour pwmServo : pins fréquence
2021-06-02 pwm ev working
2021-06-06 odometry qui déconne
2021-06-06 del lidar test worskapce qui aurait dû être dans sa propre branche
2021-06-06 added lidar libs and pathfinding (empty) files
2021-06-07 update odometry ne marche pas
2021-06-09 update odometry & platforio
2021-06-09 rajout de nom en haut de certains fichiers, modif matchdirector car bug changement d'état
    [MatchDirector.cpp]
2021-06-09 ajout de "droit d'auteur"
2021-06-10 Ajout du code pour le display (non testé, G pas de compilateur...)
2021-06-10 updat abs to coord correct, update comm pour tests
    [MatchDirector.cpp, Secondary2021.cpp, communication.cpp]
2021-06-11 fixed bug in header include once, removed warning
    [ActionsList.cpp, controlServo.cpp, controlServo.h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]
2021-06-12 Ajout tentative de recalage roue libre + doc
2021-06-14 Ajout de flags pour la gestion des sections
2021-06-15 route table des wp de la coupe (version actuelle)
2021-06-17 Code de magie noire - le direction absolue a un pb
2021-06-18 update action list correction overflow d'actionList
    [ActionsList.cpp, MatchDirector.cpp, Secondary2021.cpp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]
2021-06-18 Match director solved merge issue reajustement
    [MatchDirector.cpp]
